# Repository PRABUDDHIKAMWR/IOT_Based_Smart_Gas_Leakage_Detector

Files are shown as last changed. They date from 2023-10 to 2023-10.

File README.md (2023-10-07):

# IOT_Based_Smart_Gas_Leakage_Detector

## Description

This project is a comprehensive solution designed to measure the concentration of LPG gas particles in the air and provide real-time updates to the user. The system is equipped with a sensor that continuously monitors the air for LPG gas particles and displays the detected level in parts per million (ppm) on a built-in screen.

One of the key features of this system is its ability to alert the user when the concentration of LPG gas exceeds a predefined threshold. This is achieved through three different types of alarm indicators: an LED indicator, an alarm buzzer, and a remote notification sent to the user's smartphone via an app. These multiple modes of alert ensure that the user is promptly and effectively notified about any potential gas leaks, thereby enhancing safety.

In addition to local monitoring and alerts, this system also supports remote monitoring. This allows users to keep track of LPG gas levels in their environment even when they are not physically present, providing an extra layer of convenience and safety.

This Gas Leakage Detector is an essential tool for anyone looking to enhance the safety of their environment by effectively monitoring and managing the risk of gas leaks.

## Table of Contents

- Installation
- Usage
- Code Examples
- Contribution Guidelines
- License
- Contact Information

## Installation 

To ensure optimal performance and safety, please follow these installation guidelines for the Gas Leakage Detector:

1. **Location**: Position the device near the gas source. Ideally, it should be placed within a distance of 50 cm from the gas source and approximately at the same height as the gas cooker.

2. **Power Source**: Ensure there is a power switch within a 1.5m radius of the device. This will allow for easy access to power the device by plugging it into a wall socket.

Please note that proper installation is crucial for the effective operation of the Gas Leakage Detector. Always refer to these guidelines when setting up your device.

## Usage

WhatsApp Image 2023-07-19 at 17 46 56

<table align = "center">
  <tr>
    <td>  </td>
    <td>  </td>
  </tr>
</table>

Three states:
<table align = "center">
  <tr>
    <td> Normal State </td>
    <td> Cooking State </td>
    <td> Leakage State </td>
  </tr>
</table>

Remote Monitoring:

<p align="center">
  Alternate Text
</p>

Follow these steps to operate the Gas Leakage Detector:

1. **Power Connection**: After mounting the device, connect it to a power source (socket) and turn on the power ON/OFF switch on the device.

2. **WiFi Connection**: Using a device such as a smartphone or laptop, connect the Gas Leakage Detector to WiFi using the access point. If you cannot connect to WiFi within 1 minute, the device will automatically operate without a WiFi connection.

3. **Remote Monitoring and Alerting**: For remote monitoring and alerting, it is necessary to connect the device to WiFi. If you cannot connect when prompted, press the second button on the device to initiate WiFi connection.

4. **Gas Source Usage**: When using the gas source, if the device indicates a gas leakage, press the first button on the device to avoid continuous alerting. This will activate 'Cooking Mode'. Once you turn off the gas source and the LPG concentration in the air decreases, the device will automatically return to normal operation.

5. **Safety Measures**: If you experience a gas leakage, take appropriate safety measures to prevent any accidents.

Remember, proper usage is crucial for ensuring effective operation and safety with the Gas Leakage Detector.

## Code Examples

Here are some key functions in our Gas Leakage Detector code:

1. **measure_ppm()**: This function measures the concentration of LPG gas in the air.

```c++
void measure_ppm() {
  float LPGAvg = 0;
  for (int i = 0; i < 30; i++) {
    delay(100);
    LPGAvg += analogRead(mqpin);
  }
  LPGppm = LPGAvg;
}

void printState(String state) {
  Serial.print("LPG ppm: ");
  Serial.print(LPGppm);
  Serial.println(" ppm");
  display.clearDisplay();
  print_line(state, 26, 45, 2);
  print_line("LPG concentration :", 0, 0, 1);
  display.setCursor(26, 20);
  print_line(String(LPGppm) + " ppm", 26, 20, 1);
  delay(3000);
}

void connectWiFi() {
  display.clearDisplay();
  print_line("Connect to WiFi...", 1, 1, 0);
  WiFiManager wm;
  wm.resetSettings();
  wm.setConfigPortalTimeout(120); // Set connection timeout to 2 minutes
  bool res = wm.autoConnect("AutoConnectAP", "password"); // Password-protected AP

...
}
```

## Contribution Guidelines

I welcome and appreciate all contributions. Here's how you can help:

- **Reporting Issues**: If you find a bug or a mistake in the code, please report it by opening a new issue in the GitHub repository.

- **Suggesting Enhancements**: If you have an idea for a new feature or an improvement in the existing functionality, feel free to open an issue describing your idea.

## License

This project is licensed under the GNU General Public License (GPL). This means that you are free to use, modify, and distribute the code, but any changes or improvements must also be released under the GPL.

For the full license text, see the [LICENSE] file in this repository.

## Contact Information

For any questions or concerns about the project, feel free to reach out:

- Create an issue in [GitHub Issues].

Please understand that this is an open source project and while I strive to be responsive, there may be some delays in getting back to you.

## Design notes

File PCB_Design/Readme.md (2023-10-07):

# PCB Design

This folder contains the design files for the Printed Circuit Board (PCB) of our product. The design was created using Altium Designer version 22.4.2.

The folder includes the following files:

1. **Schematic File**: This file contains the schematic diagram of our product, detailing the connections between the components.

2. **PCB File**: This file contains the layout of the PCB, including the placement of components and routing of traces.

3. **Gerber Files**: These files are used for manufacturing the PCB. They contain information about the copper layers, solder mask, legend, and drill holes.

Schematic:


In addition, you can view images of the front and back sides of the PCB:

<table>
  <tr>
    <td> Front Side Image 1 </td>
    <td> Front Side Image 2 </td>
    <td> Front Side Image 3 </td>
  </tr>
  <tr>
    <td> Back Side Image 1 </td>
    <td> Back Side Image 2 </td>
    <td> Back Side Image 3 </td>
  </tr>
</table>

Please ensure you have Altium Designer version 22.4.2 or later to open and modify these files. If you have any questions or suggestions, feel free to open an issue.

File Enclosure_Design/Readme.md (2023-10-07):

# Enclosure Design

This folder contains the design files for the enclosure of our product. The design was created using SOLIDWORKS 2020.

The enclosure consists of two main parts:

1. **Base**: This is the bottom part of the enclosure that houses the main components of our product.

2. **Lid**: This is the top part of the enclosure that fits onto the base to protect the internal components.

Each part has been designed with precision to ensure a secure fit and proper ventilation for the internal components.

Please ensure you have SOLIDWORKS 2020 or later to open and modify these files. If you have any questions or suggestions, feel free to open an issue.
<table>
  <tr>
    <td>  </td>
    <td>  </td>
  </tr>
  <tr>
    <td>  </td>
    <td>  </td>
  </tr>
</table>

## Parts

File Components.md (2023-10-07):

# Components

This project utilizes the following components:

1. **ESP32 Microprocessor Board**: This is the main processing unit of the project. It handles inputs from various sensors and other sources.

2. **MQ2 Gas Sensor Module**: This sensor is used to measure the concentration of LPG in the air. It provides crucial data for the safety functionality of the project.

3. **PIR Sensor Module**: This module detects the presence of people. It helps the system understand when it needs to be active the some functinality on the device.

4. **OLED Display**: The OLED display shows the LPG concentration levels. It provides a user-friendly way to understand the readings from the MQ2 Gas Sensor.

5. **HLK-PM01 Power Module**: This module provides regulated voltage to the circuit from the main power supply. It ensures that all components receive a stable and safe power supply.

Each component plays a vital role in ensuring that the project functions correctly and safely.

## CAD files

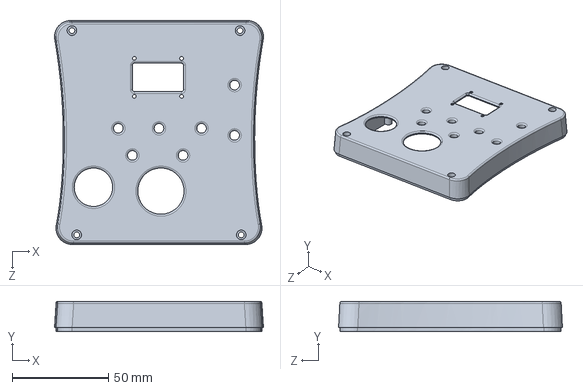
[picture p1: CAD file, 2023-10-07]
Enclosure_Design/Enclosure_Lid.SLDPRT
108.5 x 15.6 x 116.2 mm

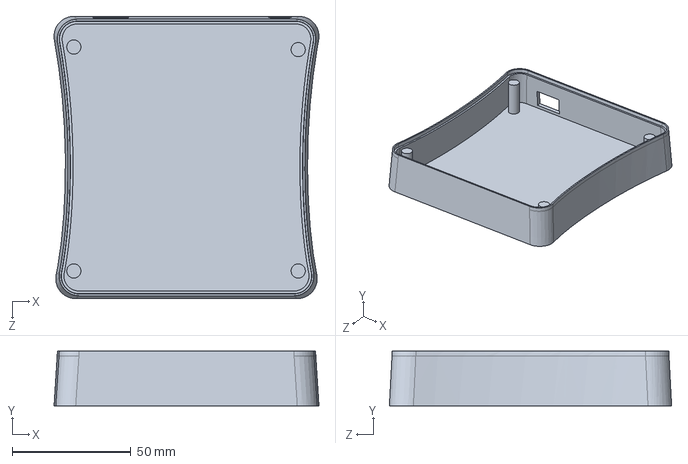
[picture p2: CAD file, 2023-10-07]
Enclosure_Design/Enclosure_Base.SLDPRT
111.4 x 23.0 x 118.6 mm

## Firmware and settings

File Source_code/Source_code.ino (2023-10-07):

#include <Wire.h>
#include <Adafruit_GFX.h>
#include <Adafruit_SSD1306.h>
#include <WiFi.h>
#include <WiFiClient.h>
#include <BlynkSimpleEsp32.h>
#include <WiFiManager.h>

// Define constants for display dimensions and I2C address
#define WIDTH 128
#define HEIGHT 64
#define RESET_PIN -1
#define OLED_ADDRESS 0x3C

// Define pin assignments for components
#define BUZZER_PIN 14
#define GREEN_LED 19
#define YELLOW_LED 18
#define RED_LED 5
#define MUTE_BUTTON 32
#define TEST_BUTTON 33
#define MQ_SENSOR_PIN 35 // Other pins: 37, 38, 39, 34, 36
#define PIR_SENSOR_PIN 27
#define MUTE_LED 15
#define TEST_LED 4

// Define Blynk template information
#define BLYNK_TEMPLATE_ID "TMPL6FNWeJsx3"
#define BLYNK_TEMPLATE_NAME "Gas Leakage Detector"
#define BLYNK_AUTH_TOKEN "cj3DAuZWEThcB4aGmqUUZbpqSrFxeLQv"

// Virtual pins for Blynk buttons
#define VPIN_BUTTON_1 V1
#define VPIN_BUTTON_2 V2

// Global variables
bool timeouted = false;
BlynkTimer timer;
Adafruit_SSD1306 display(WIDTH, HEIGHT, &Wire, RESET_PIN);

// Set trigger value for gas leakage in ppm
int leakage_ppm = 5000;
bool motion = false;
float LPGppm = 0;
bool pressed_mute = false;
int t = 0;

// Blynk authentication
char auth[] = BLYNK_AUTH_TOKEN;

// Function prototypes
void measure_ppm();
void printState(String state);
void print_line(String text, int column, int row, int textSize);
void checkBlynkStatus();
void connectWiFi();

void setup() {
  // Initialize sensor and output pins
  pinMode(MQ_SENSOR_PIN, INPUT);
  pinMode(PIR_SENSOR_PIN, INPUT);
  pinMode(BUZZER_PIN, OUTPUT);
  pinMode(GREEN_LED, OUTPUT);
  pinMode(YELLOW_LED, OUTPUT);
  pinMode(RED_LED, OUTPUT);
  pinMode(MUTE_BUTTON, INPUT);
  pinMode(TEST_BUTTON, INPUT);
  pinMode(MUTE_LED, OUTPUT);
  pinMode(TEST_LED, OUTPUT);

  // Initialize serial communication
  Serial.begin(9600);

  // Initialize OLED display
  if (!display.begin(SSD1306_SWITCHCAPVCC, OLED_ADDRESS)) {
    Serial.println(F("SSD1306 allocation failed"));
    for (;;);
  }
  delay(200);
  display.clearDisplay();

  // Display welcome message
  print_line("WELCOME", 10, 25, 2);
  delay(1000);

  display.clearDisplay();
  print_line("Gas leakage detector", 0, 20, 1.5);
  delay(1000);
  display.clearDisplay();

  // Set up Blynk connection and timer
  timer.setInterval(2000L, checkBlynkStatus); // Check Blynk server connection every 2 seconds
  Blynk.config(auth);
  delay(1000);

  // Connect to Wi-Fi
  t = millis();
  while (millis() - t < 30000) {
    if (WiFi.status() != WL_CONNECTED && !timeouted) {
      connectWiFi();
      break;
    }
  }
}

void loop() {
  // Handle Wi-Fi connection during button press
  if ((digitalRead(TEST_BUTTON) == LOW) && WiFi.status() != WL_CONNECTED) {
    t = millis();
    while (millis() - t < 30000) {
      if (WiFi.status() != WL_CONNECTED) {
        connectWiFi();
        break;
      }
    }
  }

  // Measure gas concentration
  measure_ppm();
  Serial.println(LPGppm);
  Blynk.virtualWrite(VPIN_BUTTON_1, LPGppm);

  // Check for normal gas concentration
  if (LPGppm < 200) {
    motion = false;
    pressed_mute = false;
    digitalWrite(RED_LED, LOW);
    digitalWrite(YELLOW_LED, LOW);
    digitalWrite(GREEN_LED, HIGH);
    digitalWrite(TEST_LED, LOW);
    digitalWrite(BUZZER_PIN, LOW);
    printState("NORMAL");
    Blynk.virtualWrite(VPIN_BUTTON_2, "NORMAL");
  } else {
    // Check for muted state or cooking mode
    if ((digitalRead(MUTE_BUTTON) == LOW) || (pressed_mute == true)) {
      Serial.println("MUTED");
      motion = false;
      pressed_mute = true;
      digitalWrite(RED_LED, LOW);
      digitalWrite(GREEN_LED, LOW);
      digitalWrite(YELLOW_LED, HIGH);
      digitalWrite(TEST_LED, LOW);
      digitalWrite(BUZZER_PIN, LOW);
      printState("COOKING");
      Blynk.virtualWrite(VPIN_BUTTON_2, "COOKING");
    } else {
      t = millis();
      while (((millis() - t) < 2000) && (!(motion))) {
        // Check for motion detection
        if (digitalRead(PIR_SENSOR_PIN)) {
          motion = true;
          Serial.println("Motion detected ");
          digitalWrite(TEST_LED, HIGH);
          print_line("Motion detected during leakage", 0, 0, 2);
          delay(500);
          break;
        }
        // Check for mute button press
        if (digitalRead(MUTE_BUTTON) == LOW) {
          pressed_mute = true;
          digitalWrite(TEST_LED, LOW);
        }
      }
      if (!(motion)) {
        delay(500);
        Blynk.logEvent("leakage_alert", "Gas Leakage Detected!");
      }
      digitalWrite(GREEN_LED, LOW);
      digitalWrite(YELLOW_LED, LOW);
      digitalWrite(RED_LED, HIGH);
      digitalWrite(BUZZER_PIN, HIGH);
      print_line("Hold mute button to mute", 0, 17, 1);
      printState("LEAKAGE");
      Blynk.virtualWrite(VPIN_BUTTON_2, "LEAKAGE");
      digitalWrite(RED_LED, LOW);
      digitalWrite(BUZZER_PIN, LOW);
      delay(500);
    }
  }
  Blynk.run();
  timer.run();
}

// Function to measure gas concentration in ppm
void measure_ppm() {
  float LPGAvg = 0;
  for (int i = 0; i < 30; i++) {
    delay(100);
    LPGAvg += analogRead(MQ_SENSOR_PIN);
  }
  LPGppm = map(LPGAvg / 30, 0, 4095, 200, 10000);
  LPGppm = LPGAvg;
}

// Function to print system state information
void printState(String state) {
  Serial.print("LPG ppm: ");
  Serial.print(LPGppm);
  Serial.println(" ppm");
  display.clearDisplay();
  print_line(state, 26, 45, 2);
  print_line("LPG concentration:", 0, 0, 1);
  display.setCursor(26, 20);
  print_line(String(LPGppm) + " ppm", 26, 20, 1);
  delay(3000);
}

// Function to print text on the OLED display
void print_line(String text, int column, int row, int textSize) {
  display.setTextSize(textSize);
  display.setTextColor(SSD1306_WHITE);
  display.setCursor(column, row);
  display.println(text);
  display.display();
}

// Function to check Blynk server status
void checkBlynkStatus() {
  bool isconnected = Blynk.connected();
  if (isconnected == false) {
    Serial.println("Blynk Not Connected");
    digitalWrite(MUTE_LED, LOW);
  }
  if (isconnected == true) {
    digitalWrite(MUTE_LED, HIGH);
    Serial.println("Blynk Connected");
  }
}

// Function to connect to Wi-Fi using WiFiManager
void connectWiFi() {
  display.clearDisplay();
  print_line("Connect to WiFi...", 1, 1, 0);
  WiFiManager wm;
  wm.resetSettings();
  wm.setConfigPortalTimeout(120); // Set connection timeout to 2 minutes
  bool res = wm.autoConnect("AutoConnectAP", "password"); // Password-protected AP

  if (res) {
    Serial.println("Connected to WiFi");
    display.clearDisplay();
    digitalWrite(MUTE_LED, HIGH);
    print_line("Connected to WiFi", 1, 1, 0);
    delay(2);
    return; // Exit the function on successful connection
  } else {
    Serial.println("Failed to connect to WiFi");
    display.clearDisplay();
    timeouted = true;
    print_line("WiFi connection failed", 1, 1, 0);
    delay(2);
    return; // Exit the function on failure
  }
}
